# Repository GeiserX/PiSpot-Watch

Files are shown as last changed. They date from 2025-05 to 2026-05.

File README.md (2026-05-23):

> **⚠️ This project is archived.** Last active development was in 2018. The code is preserved here for reference purposes only and is no longer maintained.

<p align="center">PiSpot Watch banner</p>

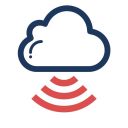
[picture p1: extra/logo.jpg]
PiSpot Watch logo


<h1 align="center">PiSpot Watch</h1>

<p align="center">
  <strong>A wrist-wearable Raspberry Pi Zero smartwatch with an e-ink display that generates Wi-Fi voucher codes on demand.</strong>
</p>

<p align="center">
  
  
  
  
  
</p>

---

## Overview

PiSpot Watch is a custom-built wearable IoT device designed for hotel and venue staff. Press a button on your wrist and instantly generate a time-limited Wi-Fi voucher code, displayed on a low-power e-ink screen. The device communicates with the [Spotipo](https://www.spotipo.com/) captive-portal API and retrieves per-device configuration securely from [HashiCorp Vault](https://www.vaultproject.io/).

Originally developed and deployed in 2018 for the company GPConnect, this project has been released as open-source. It is part of the **PiSpot ecosystem**:

| Project | Description |
|---|---|
| **PiSpot Watch** (this repo) | Wrist-wearable e-ink voucher device |
| [PiSpot Show](https://github.com/GeiserX/PiSpot-Show) | HDMI kiosk display for lobby TVs |
| [PiSpot Deployment](https://github.com/GeiserX/PiSpot-Deployment) | Fleet provisioning and Vault configuration |

---

## Features

- **Wearable form factor** -- fully 3D-printed wristwatch case housing a Raspberry Pi Zero, PaPiRus e-ink HAT, and battery.
- **One-press voucher generation** -- each of the 4 configurable buttons creates a voucher with different duration presets via the Spotipo API.
- **E-ink display** -- 2.0" PaPiRus Zero electronic paper screen; always readable in sunlight, ultra-low power draw, holds image with no power.
- **HashiCorp Vault integration** -- per-device secrets (API keys, button mappings, speed limits) stored centrally and fetched at runtime via AppRole authentication.
- **Low-battery shutdown** -- JuiceBox battery monitor triggers graceful poweroff before the battery dies.
- **Centralized logging** -- FluentBit ships rotating logs to a remote aggregator.
- **Ansible deployment** -- single playbook provisions the entire device: drivers, services, Vault credentials, WiFi, power management.
- **Power-optimized** -- GPU memory reduced to 16 MB, HDMI disabled, ACT LED off, event-driven GPIO (no polling).

---

## Videos

### In Action

PiSpot Watch In Action (http://www.youtube.com/watch?v=wfsdekCCtP0 "PiSpot Watch In Action")

PiSpot Watch In Action 2 (http://www.youtube.com/watch?v=Iu0-R4fZw-Q "PiSpot Watch In Action 2")

### Assembly

PiSpot Watch Assembly (http://www.youtube.com/watch?v=riw7c_wJmEY "PiSpot Watch Assembly")

### Disassembly

PiSpot Watch Disassembly (http://www.youtube.com/watch?v=lueef-ptVpc "PiSpot Watch Disassembly")

---

## Photos

<p align="center">
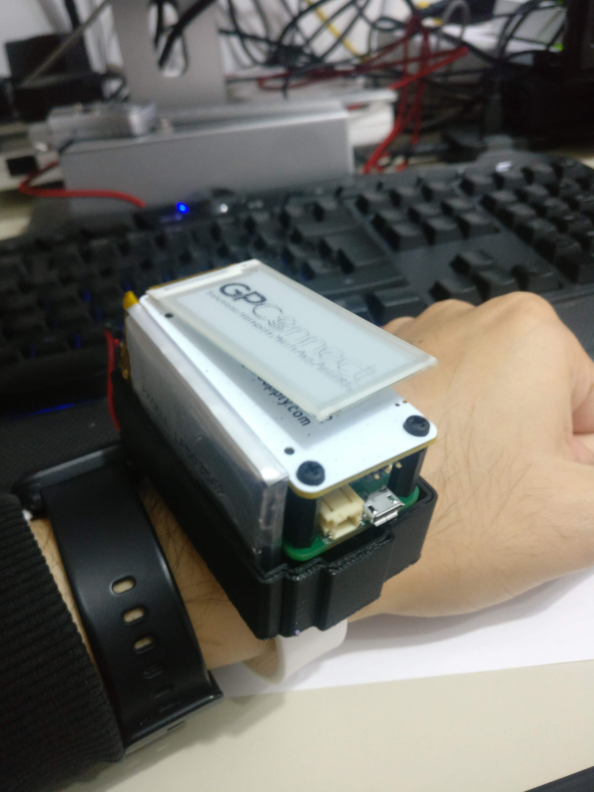
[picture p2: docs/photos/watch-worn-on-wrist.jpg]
PiSpot Watch worn on wrist
  
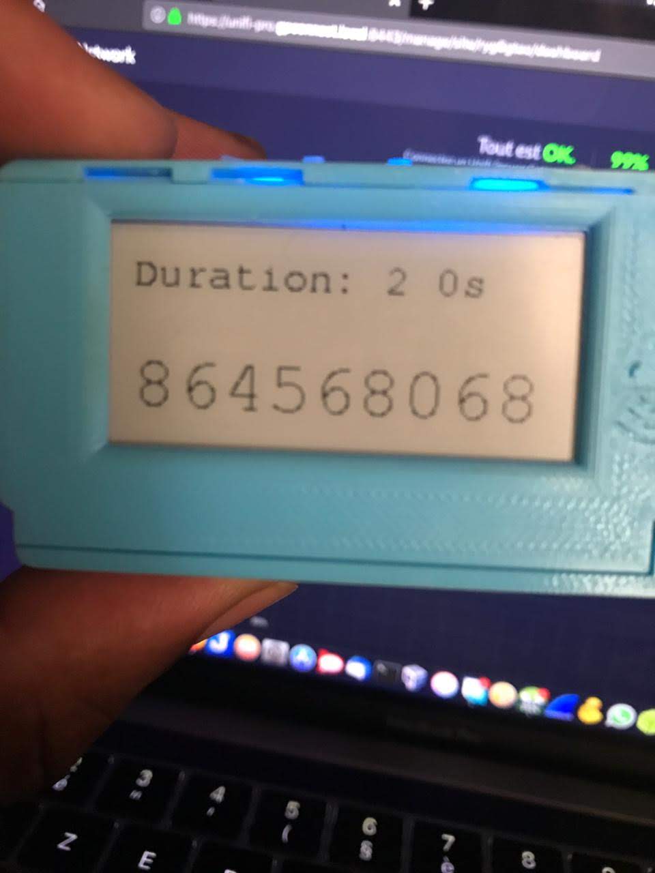
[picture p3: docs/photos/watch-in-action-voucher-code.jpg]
PiSpot Watch showing voucher code
  
</p>
<p align="center">
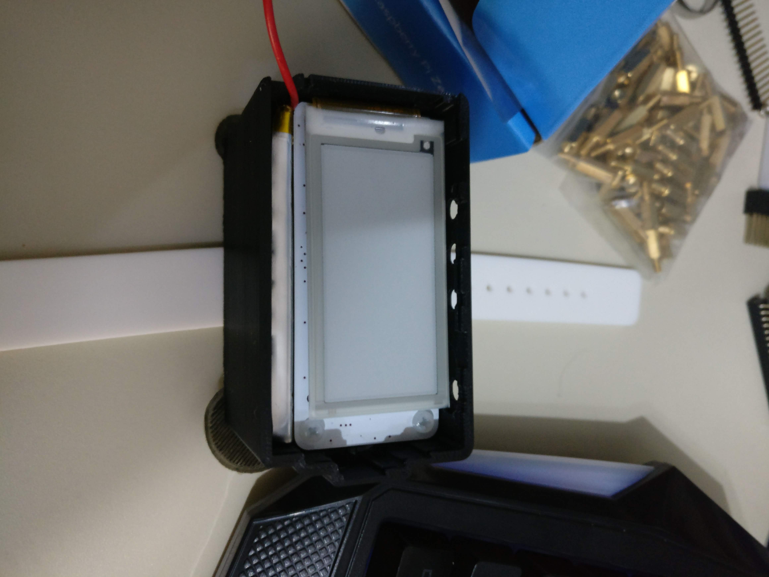
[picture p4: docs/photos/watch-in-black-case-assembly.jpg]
Watch in black 3D-printed case
  
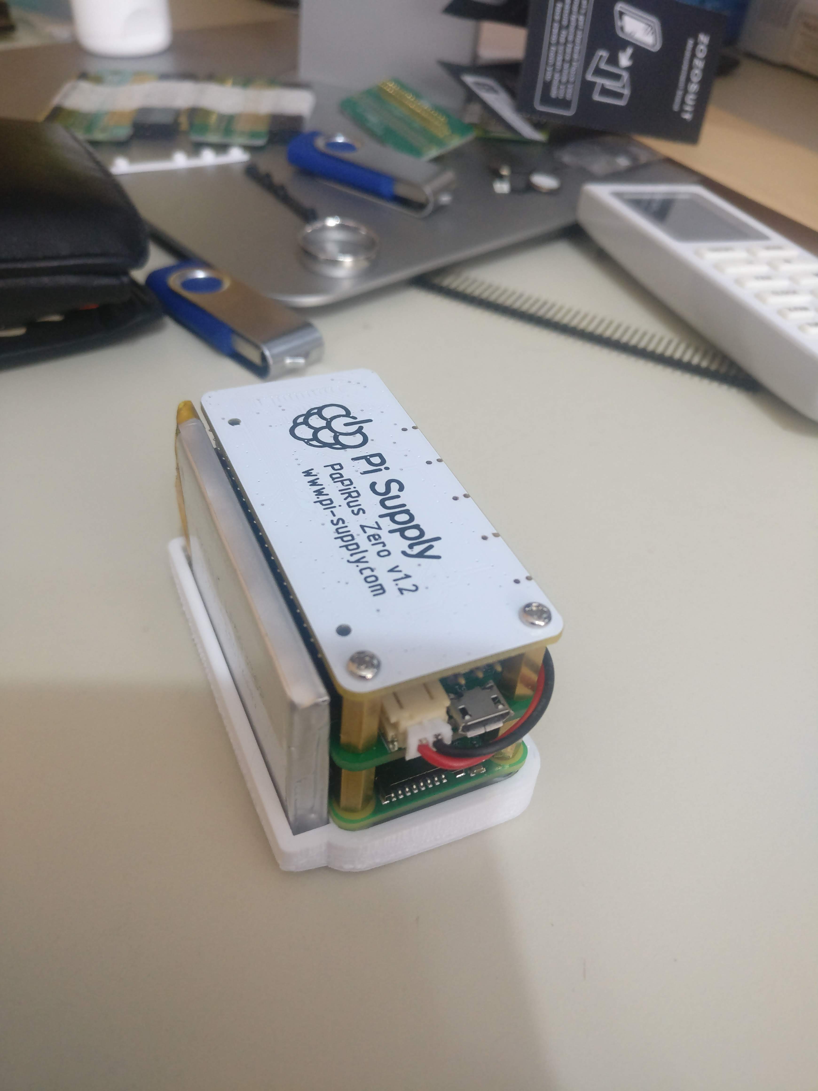
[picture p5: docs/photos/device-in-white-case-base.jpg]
Device in white case base
  
</p>
<p align="center">
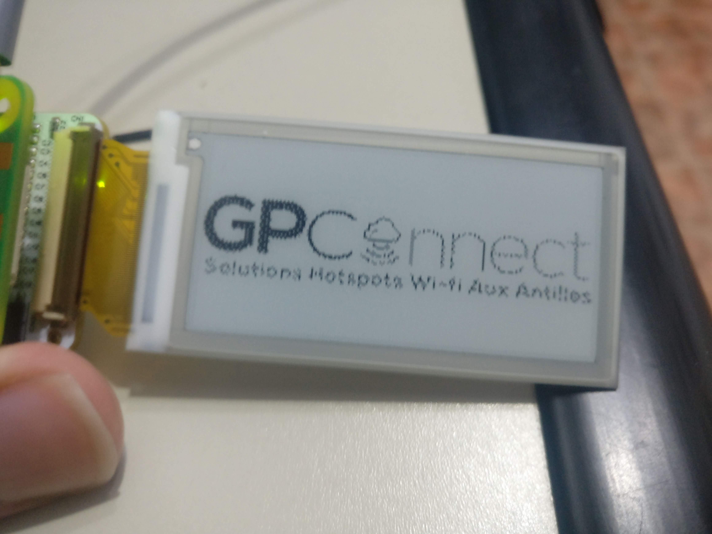
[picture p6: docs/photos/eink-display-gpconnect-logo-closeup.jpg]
E-ink display with GPConnect logo
  
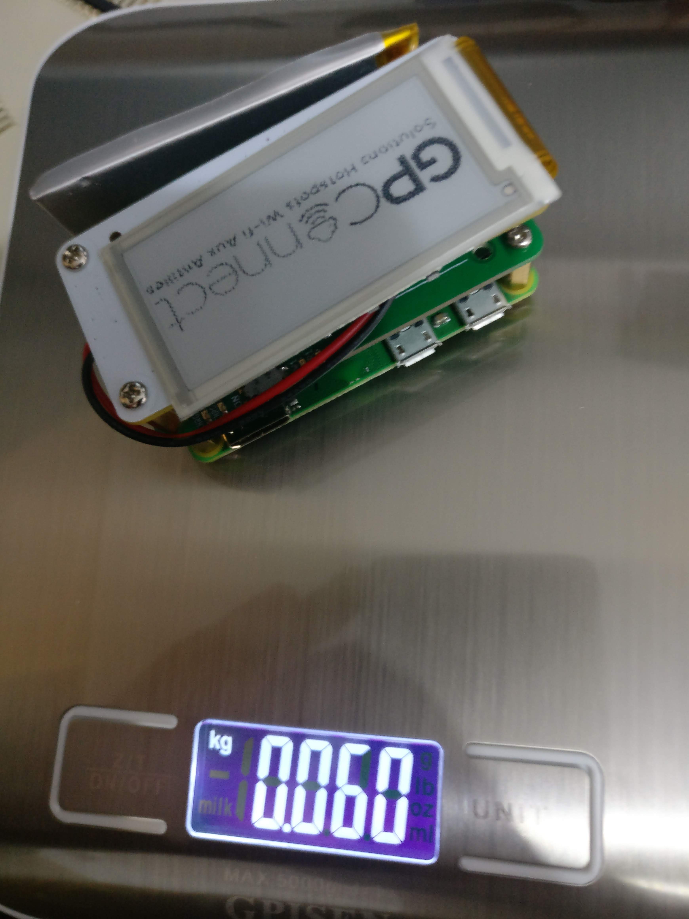
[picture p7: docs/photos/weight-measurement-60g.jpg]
Device weighing 60g on scale
  
</p>
<p align="center">
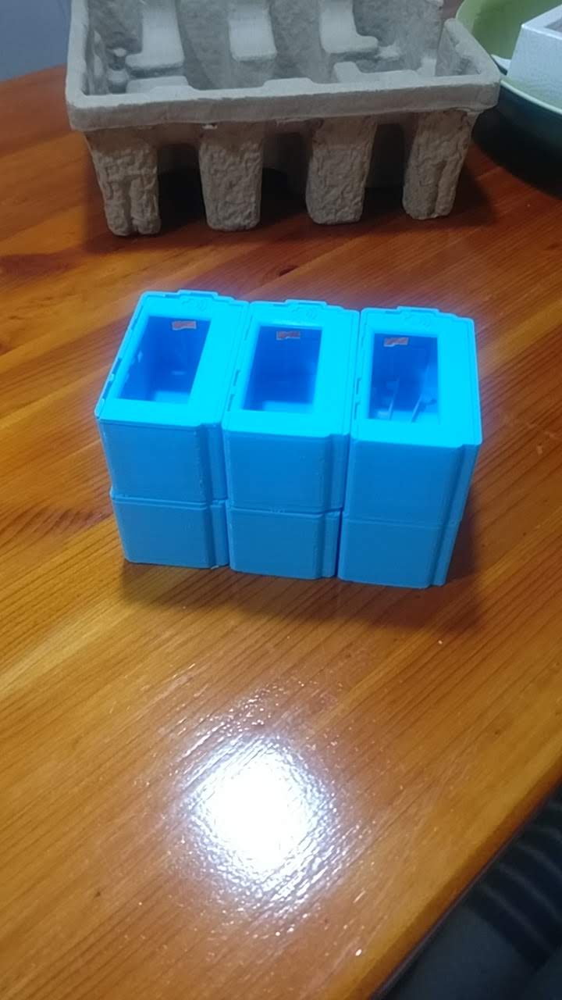
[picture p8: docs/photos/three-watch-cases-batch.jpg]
Batch of three watch cases
  
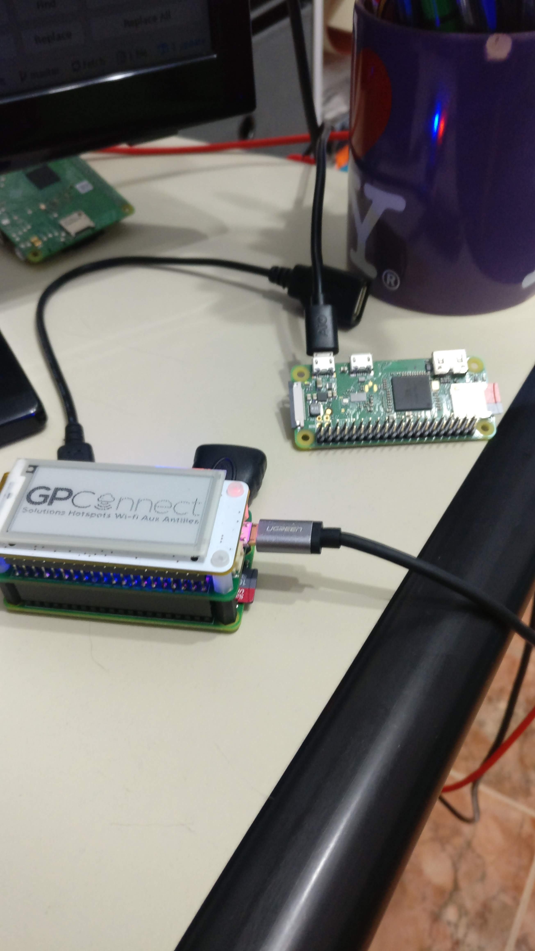
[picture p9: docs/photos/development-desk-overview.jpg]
Development desk with PiSpot devices
  
</p>

See all photos in [`docs/photos/`](docs/photos/).

---

## Hardware

| Component | Purpose |
|---|---|
| Raspberry Pi Zero | ARM processor, Wi-Fi connectivity |
| PaPiRus Zero (2.0") | E-ink display via SPI/I2C (V231_G2 panel) |
| JuiceBox battery | Wearable power supply with low-voltage shutdown |
| 5 tactile buttons | GPIO inputs: reboot (SW1) + 4 voucher presets (SW3-SW5 + optional SW2) |
| 3D-printed case | Custom enclosure with button cutouts and strap mounts |

---

## How It Works

```
  Button press (GPIO interrupt)
         |
         v
  +------+------+
  | HashiCorp   |   Fetches device config:
  | Vault       |   API key, button mappings,
  | (AppRole)   |   speed limits, duration presets
  +------+------+
         |
         v
  +------+------+
  | Spotipo     |   POST /api/voucher/create/
  | WiFi API    |   --> returns voucher code
  +------+------+
         |
         v
  +------+------+
  | PaPiRus     |   Renders duration + code
  | e-ink       |   on 2.0" e-paper display
  | display     |   (holds for 30 seconds)
  +-------------+
```

1. The device idles in a low-power loop, waiting for a GPIO falling-edge interrupt.
2. On button press, it connects to Vault and retrieves the device's secret configuration by hostname.
3. It POSTs to the Spotipo API with the voucher parameters mapped to the pressed button.
4. The voucher code and duration are rendered on the e-ink display for 30 seconds, then the screen returns to the logo.

---

## 3D-Printable Case

The `Case/` directory contains everything needed to print the wristwatch enclosure:

| File | Description |
|---|---|
| `Case.stl` | Main watch body |
| `Buttons.stl` | Physical button caps (set of 5) |
| `Cover.stl` | Protective back cover |
| `PiSpot_Voucher.fcstd` | FreeCAD parametric source (editable) |
| `*.gx` | Goxel voxel models (case, buttons, cover, assembly views) |

Multiple case variants are included (`3 Cases.gx`, `7 Buttons.gx`) for different button configurations.

---

## Getting Started

### 1. Clone

```bash
git clone https://github.com/GeiserX/PiSpot-Watch.git
```

### 2. Set up Vault secrets

Use [PiSpot Deployment](https://github.com/GeiserX/PiSpot-Deployment) to configure per-device secrets in Vault, or manually create a KV secret at `pispot_voucher/<hostname>` containing the Spotipo API key, button duration mappings, speed limits, and site number.

### 3. Deploy with Ansible

```bash
ansible-playbook -i inventory deployment-files/main.yml
```

The playbook handles:
- PaPiRus driver compilation (gratis V231_G2) and SPI/I2C enablement
- Python dependencies (`RPi.GPIO`, `requests`, `hvac`)
- `pispot.service` systemd unit (auto-starts after `epd-fuse`)
- JuiceBox low-battery shutdown service
- FluentBit log aggregation
- Vault AppRole token bootstrap and weekly renewal cron job
- WiFi configuration and power optimizations

---

## Project Structure

```
PiSpot-Watch/
  main.py                          # Main application (GPIO events + API calls + display)
  deployment-files/
    main.yml                       # Ansible provisioning playbook (288 lines)
    get-approle-token.py           # Unwraps Vault AppRole wrapped secret ID
    vault-renew-token-pi.py        # Weekly Vault token renewal (cron)
    pispot.service                 # Main app systemd unit
    low-battery-shutdown.service   # JuiceBox battery monitor unit
    papirus-clear.service          # Clears e-ink on shutdown
    td-agent-bit.conf              # FluentBit log shipping config
    wpa_supplicant.conf            # WiFi network config
  Case/                            # 3D enclosure (FreeCAD + Goxel + STL)
  docs/images/                     # Documentation assets
  extra/                           # Logo
  LICENSE                          # GPL-3.0
```

---

## License

[GNU General Public License v3.0](LICENSE)

## Maintainers

[@GeiserX](https://github.com/GeiserX)

## Contributing

Contributions are welcome. [Open an issue](https://github.com/GeiserX/PiSpot-Watch/issues/new) or submit a pull request.

This project follows the [Contributor Covenant v2.1](https://www.contributor-covenant.org/version/2/1/code_of_conduct/) Code of Conduct.

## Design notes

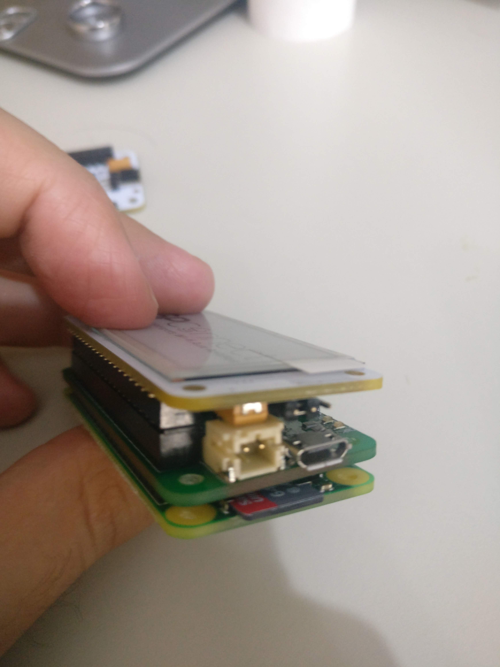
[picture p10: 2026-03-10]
docs/photos/board-stack-side-connectors.jpg

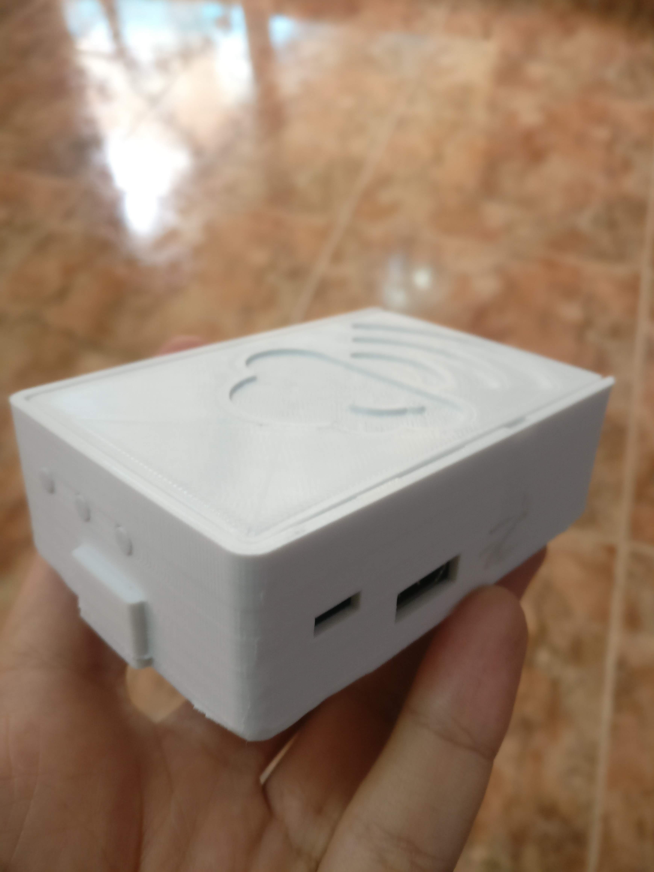
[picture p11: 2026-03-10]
docs/photos/device-with-battery-wires.jpg

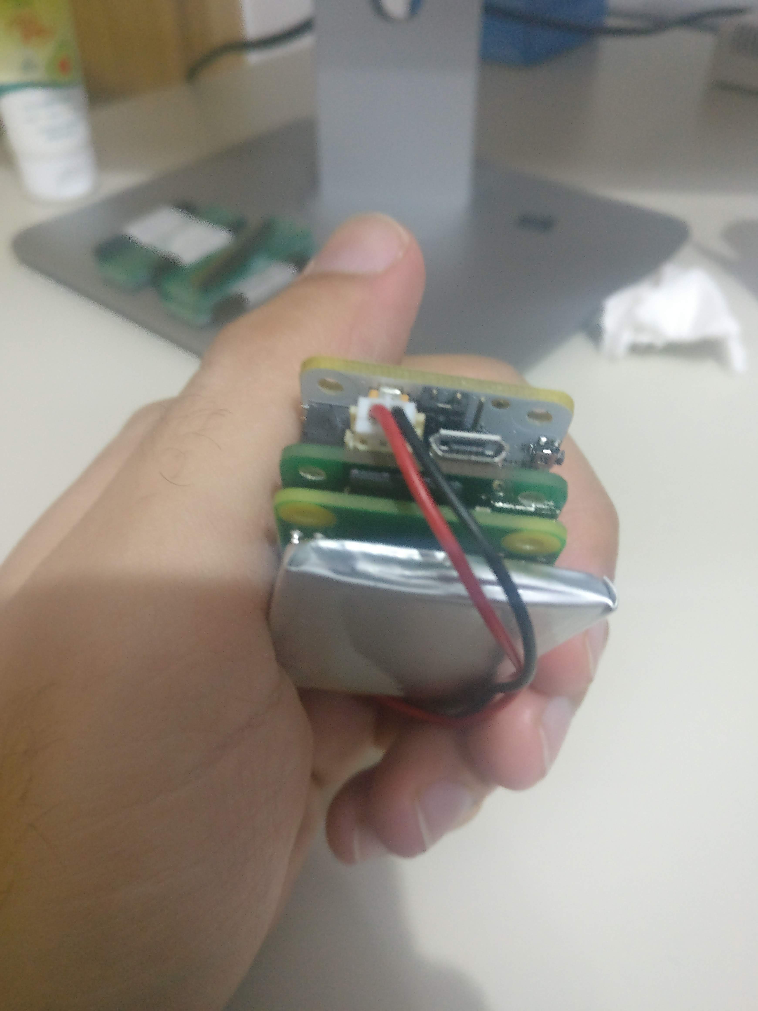
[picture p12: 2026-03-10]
docs/photos/board-stack-with-battery-back.jpg

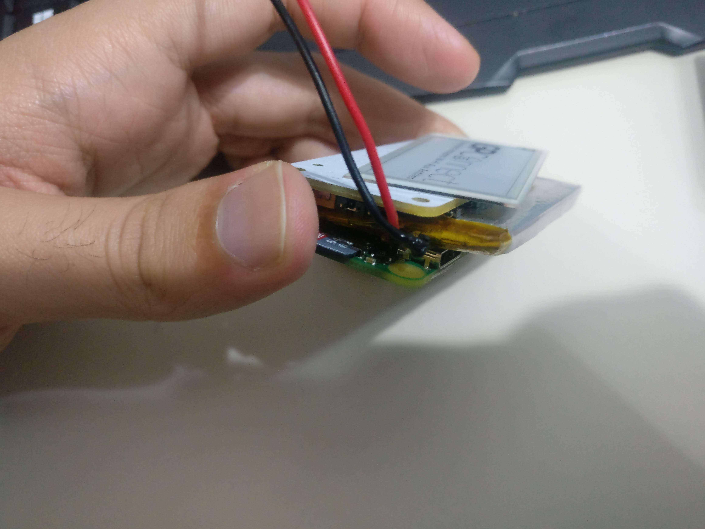
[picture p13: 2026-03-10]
docs/photos/board-stack-eink-battery-wires-held.jpg

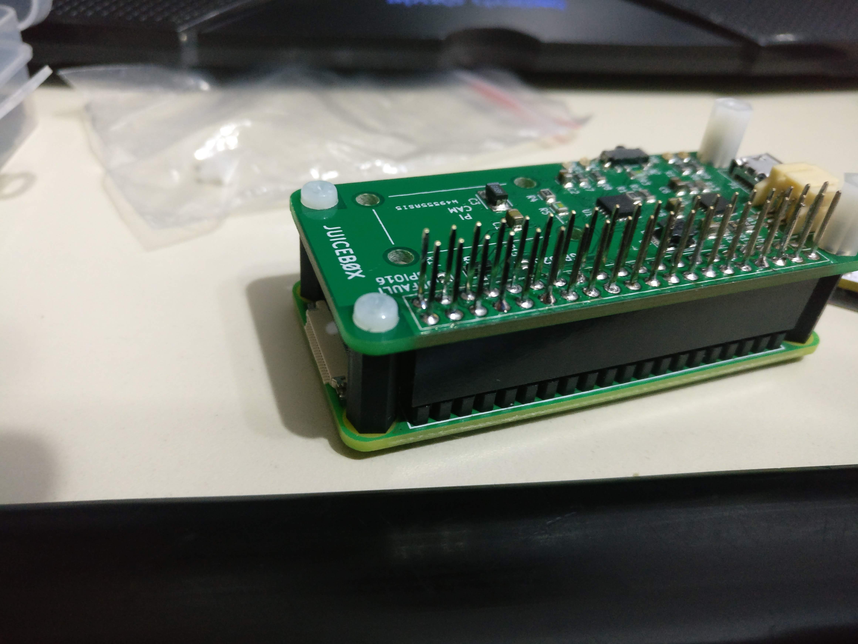
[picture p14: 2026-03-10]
docs/photos/juicebox-board-stack.jpg

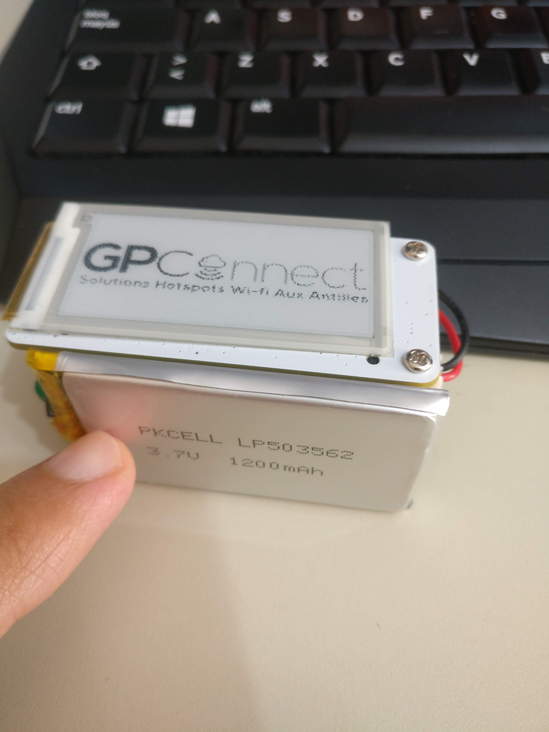
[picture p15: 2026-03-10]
docs/photos/eink-with-battery-gpconnect.jpg

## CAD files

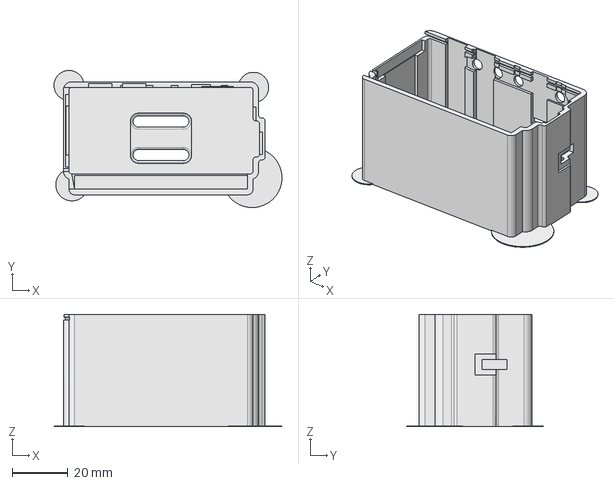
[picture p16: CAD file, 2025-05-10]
Case/PiSpot_Voucher.fcstd
81.7 x 49.1 x 40.2 mm

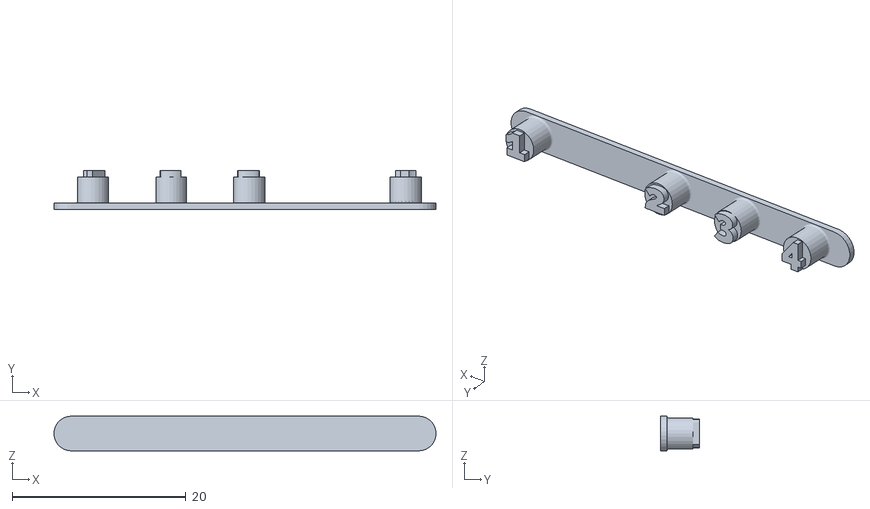
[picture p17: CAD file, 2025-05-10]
Case/Buttons.stl
44.0 x 4.45 x 4.00

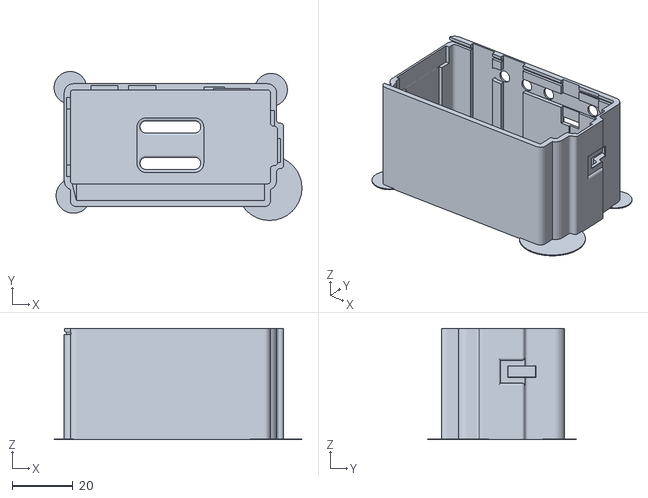
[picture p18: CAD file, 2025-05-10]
Case/Case.stl
81.7 x 49.1 x 36.8

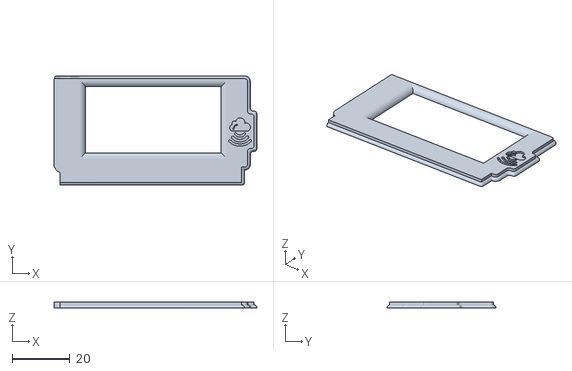
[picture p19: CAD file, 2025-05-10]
Case/Cover.stl
70.5 x 38.0 x 2.00

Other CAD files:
Case/PiSpot_Voucher_reduced.fcstd

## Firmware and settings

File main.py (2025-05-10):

#!/usr/bin/python3
import RPi.GPIO as GPIO
import requests
from papirus import PapirusImage
from papirus import PapirusTextPos
from papirus import PapirusText
import json
import time
import os
from datetime import datetime
import sys
import hvac
import logging
import logging.handlers

def click(pressed_channel):
    for channel in channels:
        GPIO.remove_event_detect(channel)
    logging.info("Switch " + str(switches.index(pressed_channel) + 1) + " pressed")

    try:
        client = hvac.Client(url = os.environ['VAULT_ADDR'], token = os.environ['VAULT_TOKEN'])
        client.secrets.kv.default_kv_version = "1"
        vault_response = client.secrets.kv.read_secret(mount_point = 'pispot_voucher', path = os.uname()[1])
    except Exception as e:
        for channel in channels:
            try:
                GPIO.add_event_detect(channel, GPIO.RISING, callback=click, bouncetime=200)
            except RuntimeError as ex:
                logging.exception(repr(ex))

        typeException = type(e).__name__
        logging.exception(e)
        sys.stdout.flush()
        text = PapirusText(rotation = rot)
        text.write(typeException)
        time.sleep(5)

        image = PapirusImage(rotation = rot)
        image.write(wd + '/logoGPConnect.png')

        return

    duration="0"
    if pressed_channel==21: os.system('sudo reboot'); return
    #elif pressed_channel==16: duration=""
    elif pressed_channel==20: duration=vault_response['data']['button_2'] # SW3
    elif pressed_channel==19: duration=vault_response['data']['button_3'] # SW4
    elif pressed_channel==26: duration=vault_response['data']['button_4'] # SW5

    plural = ""
    if duration != 1:
        plural = "s"

    duration_type="0"
    if vault_response['data']['duration_type']==1: duration_type = "minute"
    elif vault_response['data']['duration_type']==2: duration_type = "hour"
    elif vault_response['data']['duration_type']==3: duration_type = "day"

    tokenSpotipo = vault_response['data']['spotipo_key']

    spotipoURL = os.environ['SPOTIPO_URL'] #'https://access.your-net.us/s/X/api/voucher/create/'
    spotipoFullURL = spotipoURL + '/s/' + str(vault_response['data']['site_number']) + '/api/voucher/create/'
    headers = {"Content-Type":"application/json", "Authentication-Token":tokenSpotipo}

    try:
        r = requests.post(spotipoFullURL, headers=headers, data = json.dumps({
        "duration_val": duration,
        "duration_type": vault_response['data']['duration_type'],
        "batchid": vault_response['data']['batchid'],
        "number":  vault_response['data']['number'],
        "num_devices": vault_response['data']['num_devices'],
        "speed_dl":  vault_response['data']['speed_dl'],
        "speed_ul":  vault_response['data']['speed_ul'],
        "bytes_t":  vault_response['data']['bytes_t'],
        "notes": vault_response['data']['notes']
        }))

        rJSON = json.loads(r.text)
        voucher = rJSON['data']['vouchers'][0]

        text = PapirusTextPos(False, rotation = rot)
        text.AddText("Duration: " + str(duration) + " " + duration_type + plural, 10, 10, size=18, Id="Top")
        text.AddText(voucher, 10, 50, size=34, Id="Bottom")
        text.WriteAll()

        time.sleep(30) ## Wait for 30 secs to display the voucher code

        image = PapirusImage(rotation = rot)
        image.write(wd + '/logoGPConnect.png')
        logging.info("PaPiRus screen flushed")

    except Exception as e:
        typeException = type(e).__name__
        logging.exception(repr(e))
        text = PapirusText(rotation = rot)
        text.write(typeException)
        time.sleep(5)

        image = PapirusImage(rotation = rot)
        image.write(wd + '/logoGPConnect.png')

        return

    finally: # We guarantee this chunk of code to run even if an exceptions rises up
        for channel in channels:
            try:
                GPIO.add_event_detect(channel, GPIO.RISING, callback=click, bouncetime=200)
            except RuntimeError as ex:
                logging.exception(repr(ex))

    return

def main():
    global LOG_FILENAME
    LOG_FILENAME = "/var/log/pispot/main.log"

    handler = logging.handlers.RotatingFileHandler(filename=LOG_FILENAME, maxBytes=2000, backupCount=5)
    handler.setFormatter(logging.Formatter('%(asctime)s %(levelname)-8s %(message)s', '%Y-%m-%d %H:%M:%S'))

    my_logger = logging.getLogger()
    my_logger.setLevel(logging.INFO)
    my_logger.addHandler(handler)

    now = datetime.now()
    logging.info("Python3 script started at " + now.strftime("%Y-%m-%d %H:%M:%S"))

    global rot
    global switches
    global wd
    global channels

    rot = 0
    switches = [21, 16, 20, 19, 26] # The list of the switches ordered by Switch Number
    wd = os.path.dirname(os.path.realpath(__file__))

    image = PapirusImage(rotation = rot)
    image.write(wd + '/logoGPConnect.png')

    GPIO.setmode(GPIO.BCM)
    channels=[19, 20, 21, 26] # BCM19 - SW4, BCM20 - SW3, BCM21 - SW1, BCM26 - SW5
    GPIO.setup(channels, GPIO.IN)

    for channel in channels:
        GPIO.add_event_detect(channel, GPIO.FALLING, callback=click, bouncetime=200)

    while True:
        time.sleep(60)


if __name__ == "__main__":
    main()

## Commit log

2025-05-10 First commit - 2018
    [Buttons.stl, Case.stl, Cover.stl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]
2026-03-10 Add 28 project photos and in-action video links
    Photos categorized from original development (2018-2019):
    assembly stages, caliper measurements, weight test, e-ink
    display, 3D-printed cases, worn-on-wrist shot, voucher
    code in action, batch production, and development desk.
    Added two in-action YouTube video links to README.
2026-03-10 Add misplaced photo moved from PiSpot-Show
    Pi Zero + PaPiRus e-ink + LiPo battery held in hand,
    showing battery wires and board stack side.
